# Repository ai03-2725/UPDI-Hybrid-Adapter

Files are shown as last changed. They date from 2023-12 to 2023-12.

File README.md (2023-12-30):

# UPDI-Hybrid-Adapter

A CH340E-based USB-to-UPDI/serial hybrid adapter  
Designed for convenient programming and debugging of newer AVR devices.

**Warning:** Currently untested.
It is based on tested circuitry so it *should* work, but proceed at your own risk until I produce one myself and confirm its functionality.

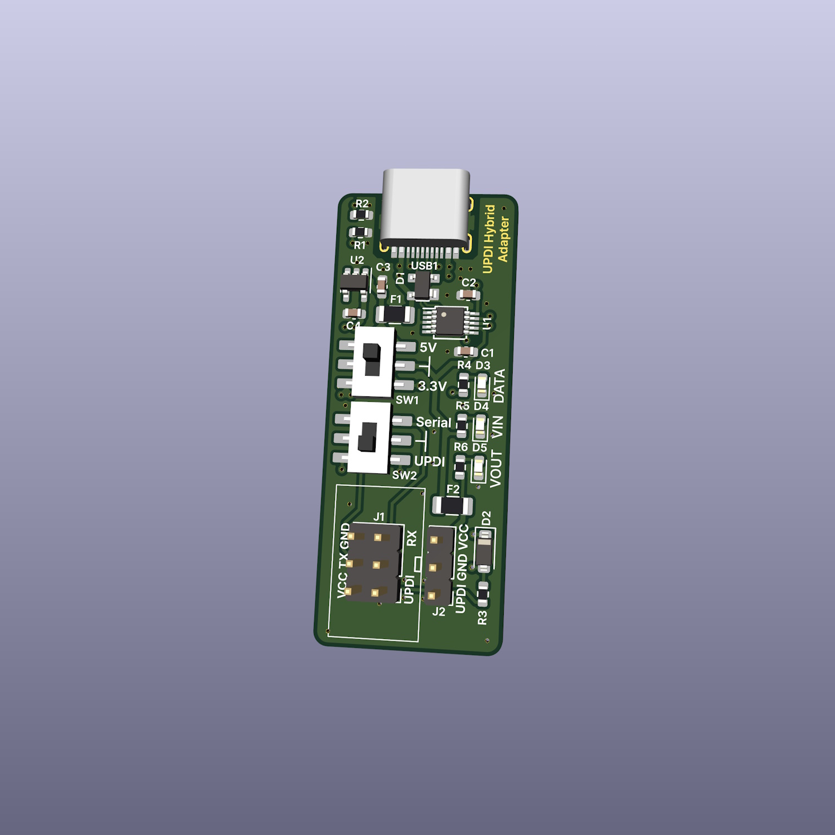
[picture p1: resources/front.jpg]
Render front

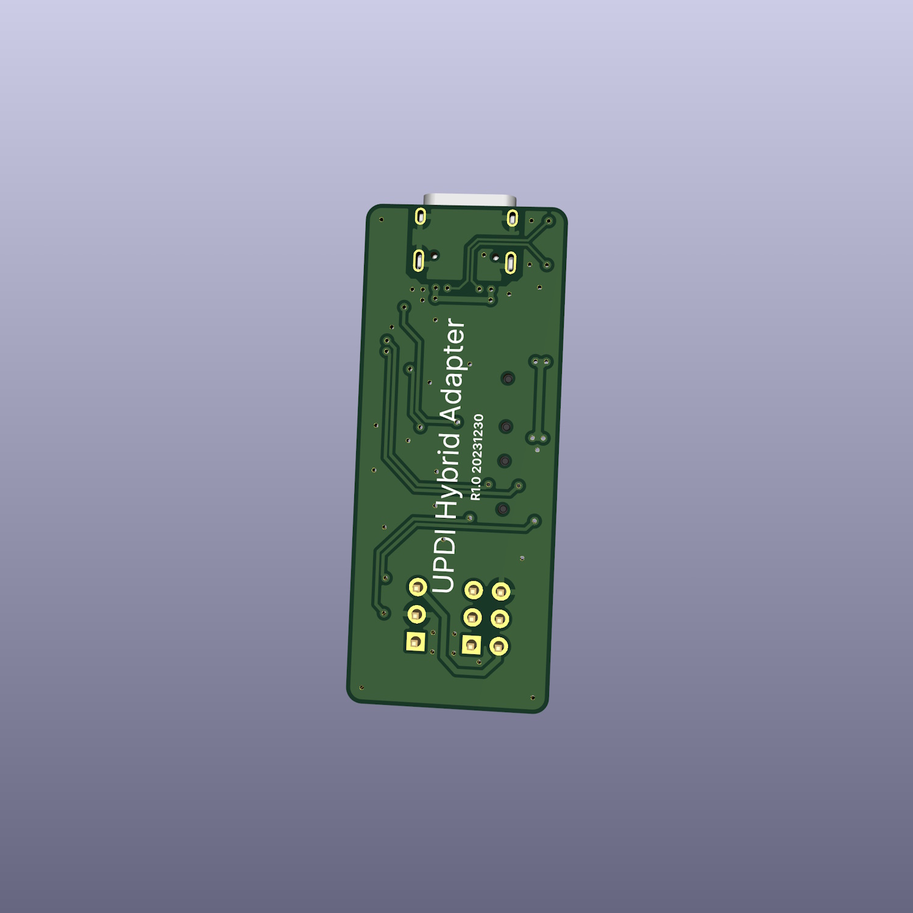
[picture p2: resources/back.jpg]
Render back


## Features

- Practicality 
  - Small 19 x 47mm form factor, connects via USB-C
  - Most components inset 1mm from the board edge to prevent accidental damage during use
  - Components only on topside for affordable PCBA and easy reflow assembly
  - Can be ordered fully assembled using JLCPCB's economic PCBA service
- Safety
  - ESD protection on USB port
  - Fused at both USB connector and output for double overcurrent protection
- Functionality
  - Selectable output voltage (5V and 3.3V)
  - Selectable UPDI programming mode or serial communications mode (TX/RX)
  - Status LEDs for data output, board power, and output/target power
  - 2x3 pin header compatible with the Tag-Connect TC2030-IDC-NL
  - 1x3 pin header for UPDI-only use

## Pinout

Please double-check the pinout and connector orientation with the silkscreen markings on the PCB.

6-pin
```
  Pin 1
|-------|-------|
| UPDI  | VCC   |
|-------|-------|
|       | TX    |
|-------|-------|
| RX    | GND   |
|-------|-------|
          Pin 6
```

3-pin
```
  Pin 1
|-------|
| UPDI  |
|-------|
| GND   |
|-------|
| VCC   |
|-------|
  Pin 3
```

## Credits

Effectively all circuitry credits go to [wagiminator's SerialUPDI Programmer](https://github.com/wagiminator/AVR-Programmer/tree/master/SerialUPDI_Programmer); the only things I did were switching out the USB connector and adding the switch to toggle the CH340's output between UPDI wiring and direct TX/RX connection.  

This project is released under the same [license](https://github.com/ai03-2725/UPDI-Hybrid-Adapter/blob/main/LICENSE) as the above.

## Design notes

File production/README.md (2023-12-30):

# Production Data

## JLCPCB files

These are JLC production BOM/position files.  
The entire unit can be ordered pre-assembled using the economic PCBA option.  

## Other data

The gerber files are located in `kicad-source/Gerber`.  
The raw (non-JLC-tuned) BOM file is located at `kicad-source/CustomUPDIProgrammer.csv`.  
The raw (non-JLC-tuned) position files are located at `kicad-source/Position`.  

## Recommended options

Select HASL-LeadFree or ENIG options - since the tool will likely be held by hand directly during use, lead-included finishes are highly discouraged.

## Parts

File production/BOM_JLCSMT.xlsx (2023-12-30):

Comment | Designator | Footprint | JLCPCB Part #（optional）
0.1uF | C1, C2 | Capacitor_SMD:C_0603_1608Metric | C14663
1uF | C3, C4 | Capacitor_SMD:C_0603_1608Metric | C15849
PRTR5V0U2X,215 | D1 | locallib:SOT143B | C12333
1N4148W | D2 | Diode_SMD:D_SOD-123 | C81598
LED-Red-0805 | D3, D4, D5 | LED_SMD:LED_0603_1608Metric | C2286
1A | F1 | Fuse:Fuse_1206_3216Metric | C910830
500mA | F2 | Fuse:Fuse_1206_3216Metric | C883126
PinHeader-2x3 | J1 | locallib:PinHeader_2x03_DC3 | C65114
PinHeader-1x3 | J2 | Connector_PinHeader_2.54mm:PinHeader_1x03_P2.54mm_Vertical | C49257
5.1k | R1, R2 | Resistor_SMD:R_0603_1608Metric | C23186
470 | R3 | Resistor_SMD:R_0603_1608Metric | C23182
1k | R4, R5, R6 | Resistor_SMD:R_0603_1608Metric | C21190
22D28 | SW1, SW2 | locallib:MS-22D28-G020 | C963205
CH340E | U1 | Package_SO:MSOP-10_3x3mm_P0.5mm | C99652
AP2112K-3.3 | U2 | Package_TO_SOT_SMD:SOT-23-5 | C51118
HRO-TYPE-C-31-M-12 | USB1 | Type-C:HRO-TYPE-C-31-M-12-Assembly | C165948

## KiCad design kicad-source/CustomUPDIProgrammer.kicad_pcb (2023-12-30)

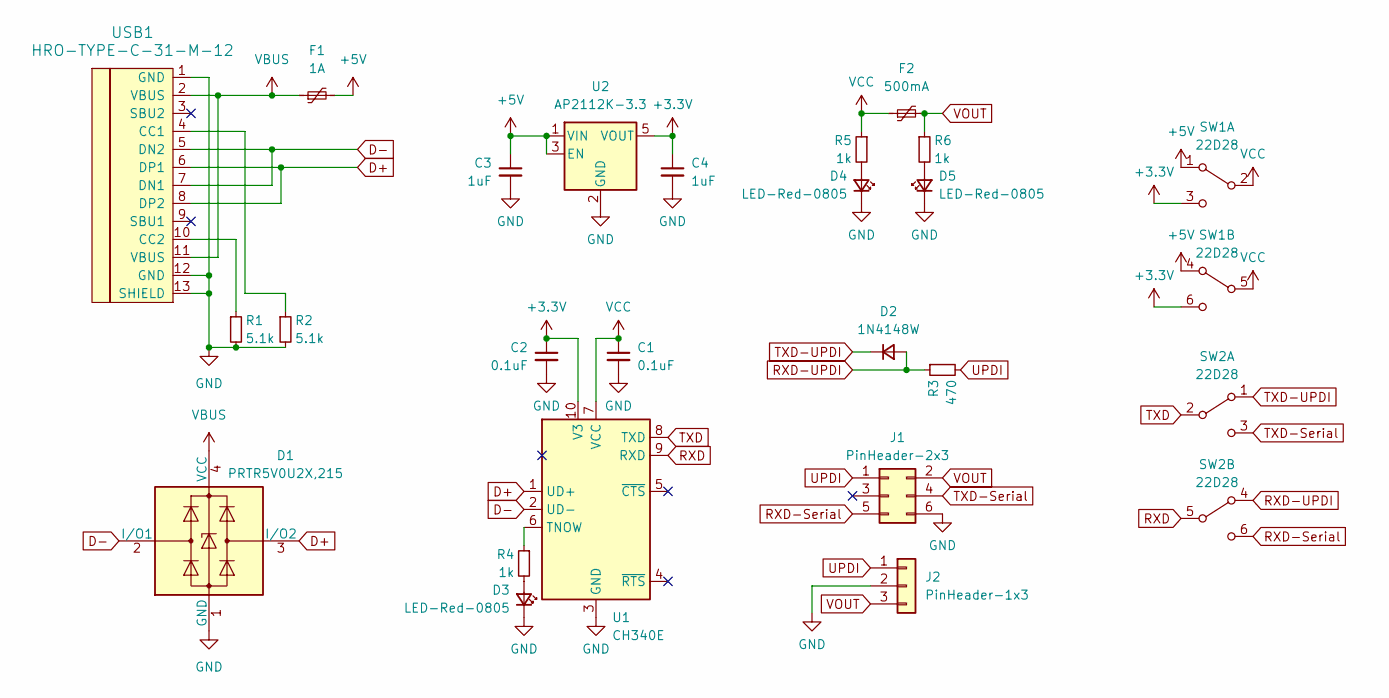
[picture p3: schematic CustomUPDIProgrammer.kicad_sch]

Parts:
C1, C2: 0.1uF; C_0603_1608Metric
C3, C4: 1uF; C_0603_1608Metric
D1: PRTR5V0U2X,215; SOT143B
D2: 1N4148W; D_SOD-123
D3, D4, D5: LED-Red-0805; LED_0603_1608Metric
F1: 1A; Fuse_1206_3216Metric
F2: 500mA; Fuse_1206_3216Metric
J1: PinHeader-2x3; PinHeader_2x03_DC3
J2: PinHeader-1x3; PinHeader_1x03_P2.54mm_Vertical
R1, R2: 5.1k; R_0603_1608Metric
R3: 470; R_0603_1608Metric
R4, R5, R6: 1k; R_0603_1608Metric
SW1, SW2: 22D28; MS-22D28-G020
U1: CH340E; MSOP-10_3x3mm_P0.5mm
U2: AP2112K-3.3; SOT-23-5
USB1: HRO-TYPE-C-31-M-12; HRO-TYPE-C-31-M-12-Assembly

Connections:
+3.3V: C2.1, C4.1, SW1.3 (C), SW1.6 (C), U1.10 (V3), U2.5 (VOUT)
+5V: C3.1, F1.2, SW1.1 (A), SW1.4 (A), U2.1 (VIN), U2.3 (EN)
D+: D1.3 (I/O2), U1.1 (UD+), USB1.6 (DP1), USB1.8 (DP2)
D-: D1.2 (I/O1), U1.2 (UD-), USB1.5 (DN2), USB1.7 (DN1)
GND: C1.2, C2.2, C3.2, C4.2, D1.1 (GND), D3.1 (K), D4.1 (K), D5.1 (K), J1.6, J2.2, R1.2, R2.2, U1.3 (GND), U2.2 (GND), USB1.1 (GND), USB1.12 (GND), USB1.13 (SHIELD)
unnamed: D3.2 (A), R4.2
unnamed: D4.2 (A), R5.2
unnamed: D5.2 (A), R6.2
unnamed: R4.1, U1.6 (TNOW)
unnamed: R2.1, USB1.4 (CC1)
unnamed: R1.1, USB1.10 (CC2)
RXD: SW2.5 (B), U1.9 (RXD)
RXD-Serial: J1.5, SW2.6 (C)
RXD-UPDI: D2.2 (A), R3.1, SW2.4 (A)
TXD: SW2.2 (B), U1.8 (TXD)
TXD-Serial: J1.4, SW2.3 (C)
TXD-UPDI: D2.1 (K), SW2.1 (A)
UPDI: J1.1, J2.1, R3.2
VBUS: D1.4 (VCC), F1.1, USB1.2 (VBUS), USB1.11 (VBUS)
VCC: C1.1, F2.1, R5.1, SW1.2 (B), SW1.5 (B), U1.7 (VCC)
VOUT: F2.2, J1.2, J2.3, R6.1

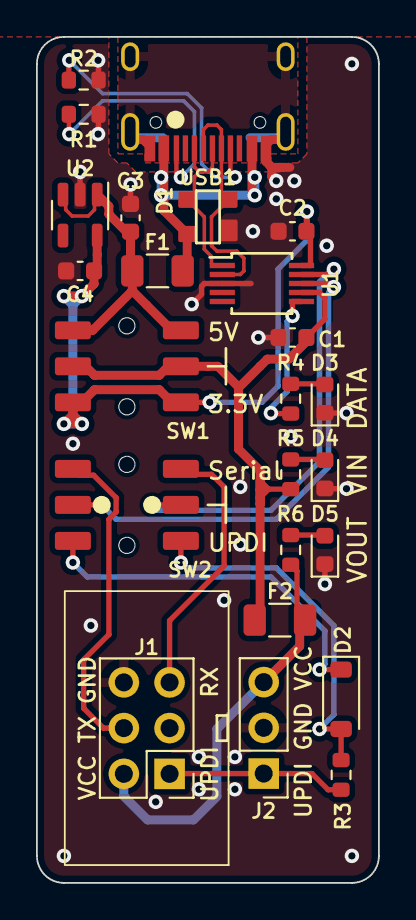
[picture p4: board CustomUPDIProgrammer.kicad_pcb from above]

Board: 2 copper layers, 19.0 x 47.0 mm, 24 parts (0 on the bottom side), 21 nets.

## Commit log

2023-12-30 Add project files
    [CustomUPDIProgrammer.kicad_pcb, CustomUPDIProgrammer.kicad_sch]
2023-12-30 Rename source folder
    [CustomUPDIProgrammer.kicad_pcb, CustomUPDIProgrammer.kicad_sch]
2023-12-30 Export gerber and BOM
    [CustomUPDIProgrammer-B_Cu.gbl, CustomUPDIProgrammer-B_Mask.gbs, CustomUPDIProgrammer-B_Paste.gbp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]
2023-12-30 Add prod files
    [BOM_JLCSMT.xlsx, CustomUPDIProgrammer.csv, CustomUPDIProgrammer.kicad_pcb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]
